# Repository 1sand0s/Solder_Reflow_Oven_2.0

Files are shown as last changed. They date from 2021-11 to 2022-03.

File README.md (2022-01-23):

# Solder Reflow Oven


 
<h2> What is it ? </h2>
A homebrew solder reflow oven controller designed around an STM32L053 series MCU with PCB layouting done in Kicad. A solder reflow oven is a device used to 
automatically solder SMD components. When dealing with integrated circuits designed to operate at high frequencies, their packages might not have leads solderable by
hand (leads can add unwanted inductance). Therefore, the only way to solder them is by using a solder reflow oven.  

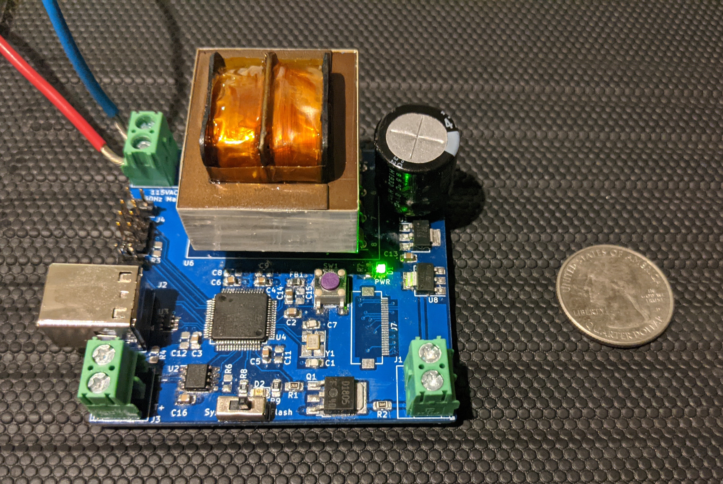
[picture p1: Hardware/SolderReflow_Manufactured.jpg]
 
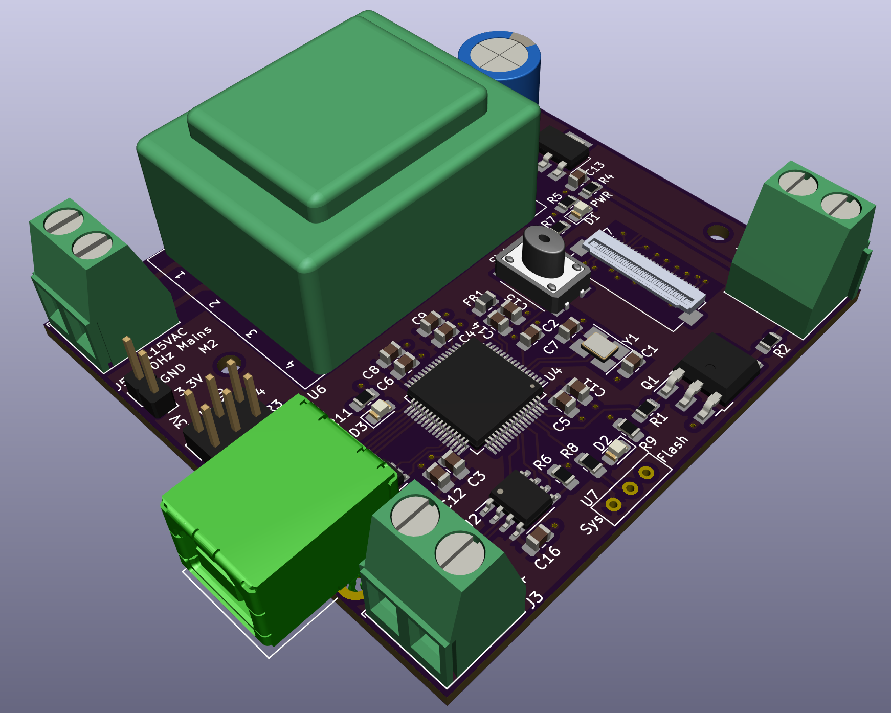
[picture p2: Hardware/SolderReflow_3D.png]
 

<h2> How does it work ? </h2>

1. The pads of the PCB are covered in solder paste, typically done with the help of a stencil

2. The components are then carefully placed on the board, the paste helps in providing adhesion to hold the components in place
 
3. The board is then placed inside the oven which controls the ambient temperature to follow a certain profile (specific to the solder paste used)
 
4. During this process the components get soldered onto the board

<h2> Heart of the Solder Reflow Oven </h2>
The heart of the solder reflow oven is the controller (the design included in this repo) which controls the ambient temperature inside the oven to follow the
specified profile. I use PID (Proportional Integrator Differentiator) control to control the ambient temperature.

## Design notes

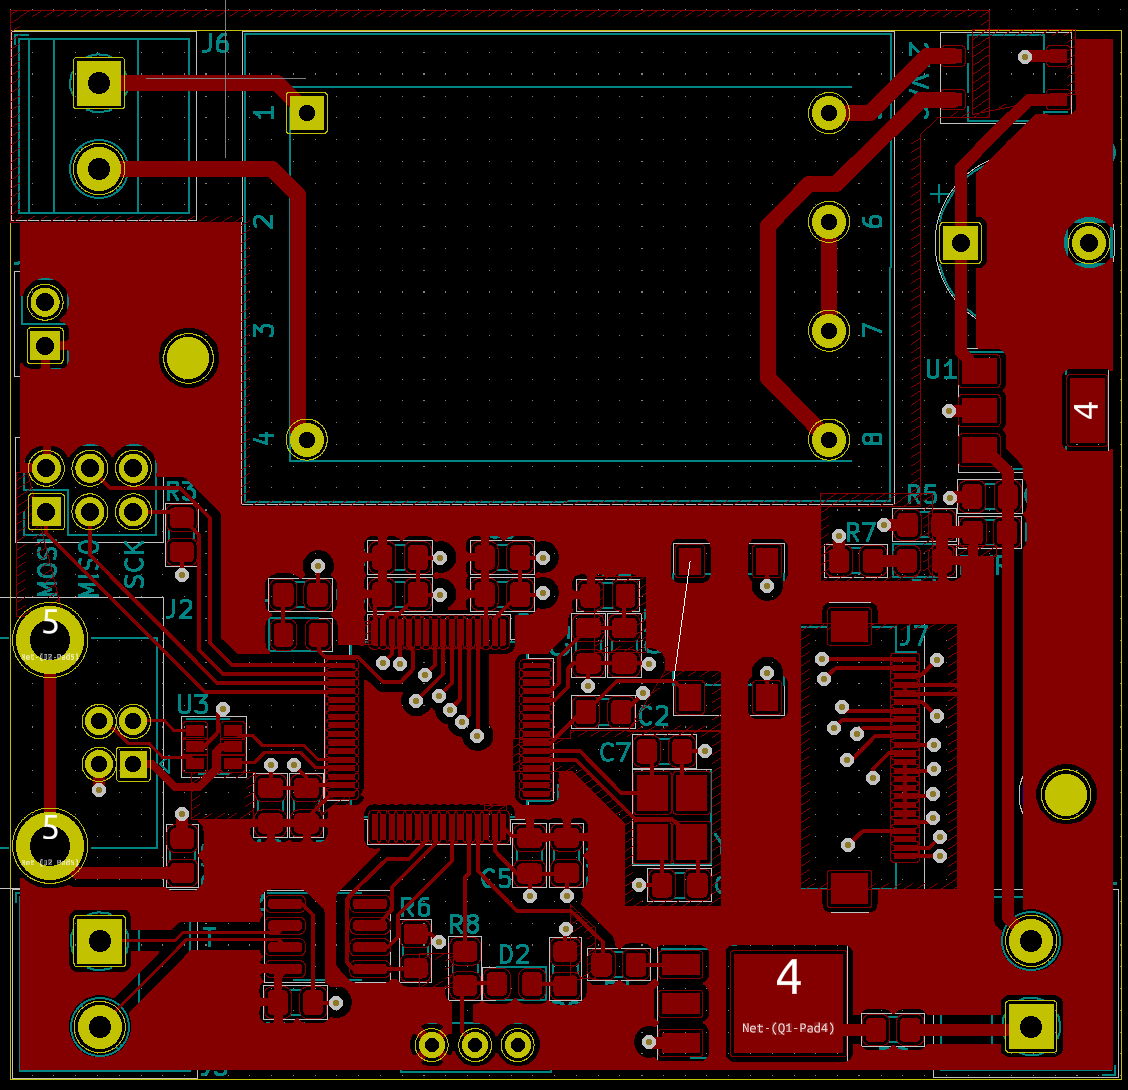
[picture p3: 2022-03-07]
Hardware/Fcu.png

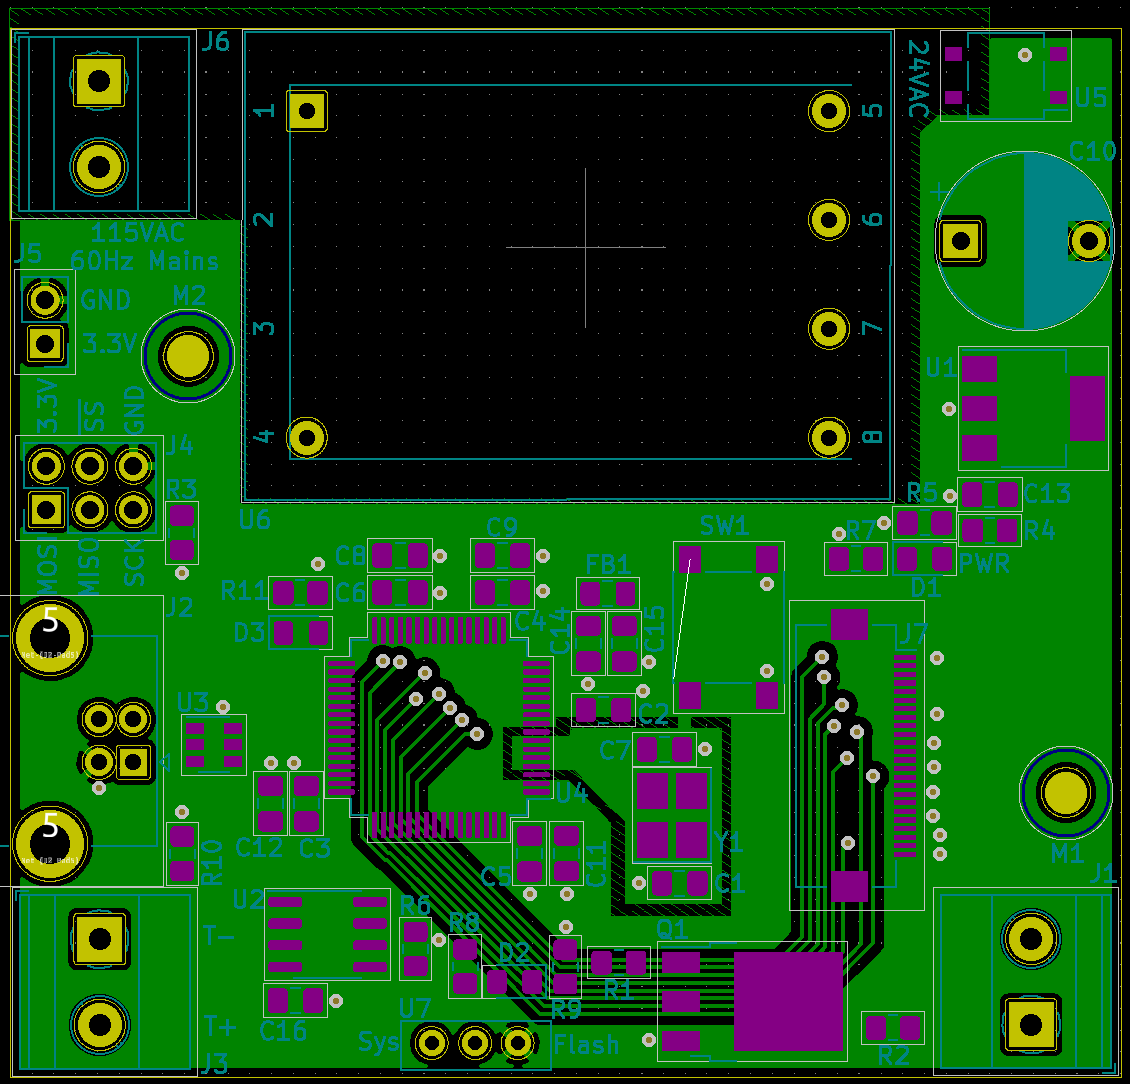
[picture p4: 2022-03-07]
Hardware/Bcu.png

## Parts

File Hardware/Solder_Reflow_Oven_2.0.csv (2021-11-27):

Id | Designator | Package | Quantity | Designation | Supplier and ref
1 | U4 | LQFP-64_10x10mm_P0.5mm | 1 | STM32L053R6T6
2 | U2 | SOIC-8_3.9x4.9mm_P1.27mm | 1 | MAX31855KASA
3 | J7 | Hirose_FH12-24S-0.5SH_1x24-1MP_P0.50mm_Horizontal | 1 | Conn_01x24_Male
4 | SW1 | SW_Push_1P1T_NO_6x6mm_H9.5mm | 1 | SW_DIP_x01
5 | C16,C2 | C_0603_1608Metric | 2 | 0.1uF
6 | R5,R7,R9 | R_0603_1608Metric_Pad0.98x0.95mm_HandSolder | 3 | 1k
7 | R4 | R_0603_1608Metric_Pad0.98x0.95mm_HandSolder | 1 | 2k
8 | C13 | C_0603_1608Metric | 1 | 22uF
9 | C10 | CP_Elec_10x14.3 | 1 | 470uF
10 | C15,C12,C11,C9,C8 | C_0603_1608Metric | 5 | 100nF
11 | C7,C1 | C_0603_1608Metric | 2 | 8pF
12 | C6,C5,C4,C3 | C_0603_1608Metric | 4 | 10uF
13 | J2 | USB_Micro-B_GCT_USB3076-30-A | 1 | USB_B_Micro
14 | FB1 | L_0402_1005Metric_Pad0.77x0.64mm_HandSolder | 1 | MMZ1005S601HTD25
15 | J1,J3,J6 | TerminalBlock_Phoenix_MKDS-1,5-2_1x02_P5.00mm_Horizontal | 3 | Conn_01x02_Male
16 | J4 | PinHeader_2x03_P2.54mm_Vertical_SMD | 1 | Conn_02x03_Top_Bottom
17 | Q1 | TO-252-3_TabPin4 | 1 | 2SD1805
18 | R1 | R_0603_1608Metric_Pad0.98x0.95mm_HandSolder | 1 | 260
19 | R2 | R_0603_1608Metric_Pad0.98x0.95mm_HandSolder | 1 | 653
20 | R3,R6,R8 | R_0603_1608Metric_Pad0.98x0.95mm_HandSolder | 3 | 10k
21 | U3 | SOT-23-6 | 1 | RCLAMP0502A.TCT
22 | U5 | TO-269AA | 1 | CDBHD140L-G
23 | Y1 | Crystal_SMD_3225-4Pin_3.2x2.5mm_HandSoldering | 1 | Crystal_GND24
24 | U1 | SOT-223 | 1 | LM2940IMPX-10/NOPB
25 | U6 | Transformer_Breve_TEZ-22x24 | 1 | F24-100-C2
26 | C14 | C_0603_1608Metric | 1 | 1uF
27 | J5 | PinHeader_1x02_P2.54mm_Vertical_SMD_Pin1Left | 1 | Conn_01x02_Top_Bottom
28 | D1,D2 | LED_0603_1608Metric_Pad1.05x0.95mm_HandSolder | 2 | LED
29 | U7 | SPDT_Reflow | 1 | SPDT_Reflow

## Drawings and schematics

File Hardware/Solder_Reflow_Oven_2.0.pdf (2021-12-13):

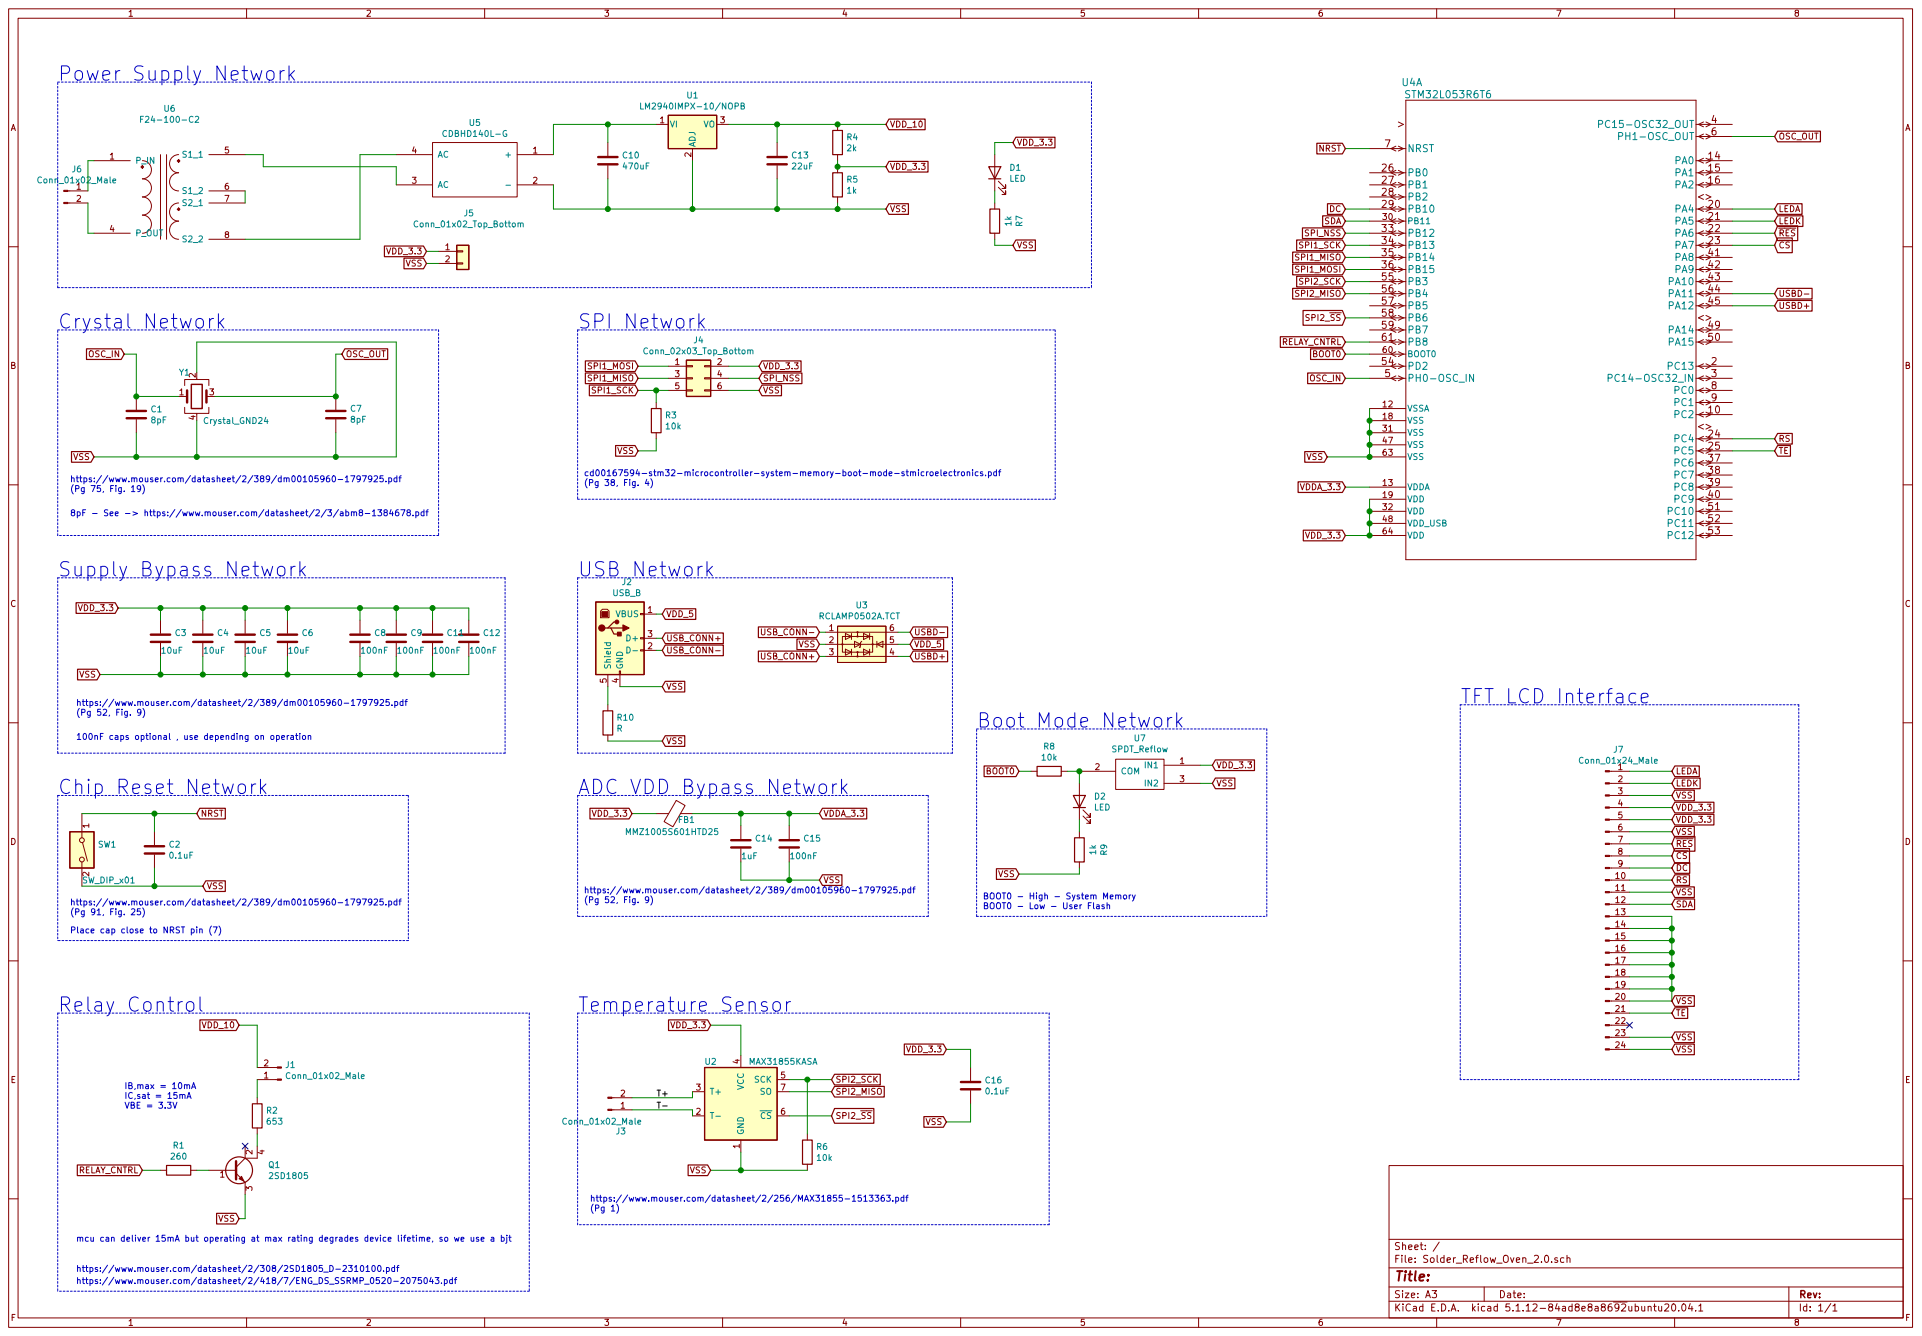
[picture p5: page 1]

https://www.mouser.com/datasheet/2/389/dm00105960-1797925.pdf
(Pg 75, Fig. 19)

cd00167594-stm32-microcontroller-system-memory-boot-mode-stmicroelectronics.pdf
(Pg 38, Fig. 4)

8pF - See -> https://www.mouser.com/datasheet/2/3/abm8-1384678.pdf

(Pg 52, Fig. 9)

100nF caps optional , use depending on operation
T+T- Chip Reset Network

ADC VDD Bypass Network

https://www.mouser.com/datasheet/2/389/dm00105960-1797925.pdf (Pg 52, Fig. 9)

BOOT0 - High - System Memory BOOT0 - Low - User Flash

(Pg 91, Fig. 25)
Place cap close to NRST pin (7)

https://www.mouser.com/datasheet/2/256/MAX31855-1513363.pdf

mcu can deliver 15mA but operating at max rating degrades device lifetime, so we use a bjt

https://www.mouser.com/datasheet/2/308/2SD1805_D-2310100.pdf
https://www.mouser.com/datasheet/2/418/7/ENG_DS_SSRMP_0520-2075043.pdf

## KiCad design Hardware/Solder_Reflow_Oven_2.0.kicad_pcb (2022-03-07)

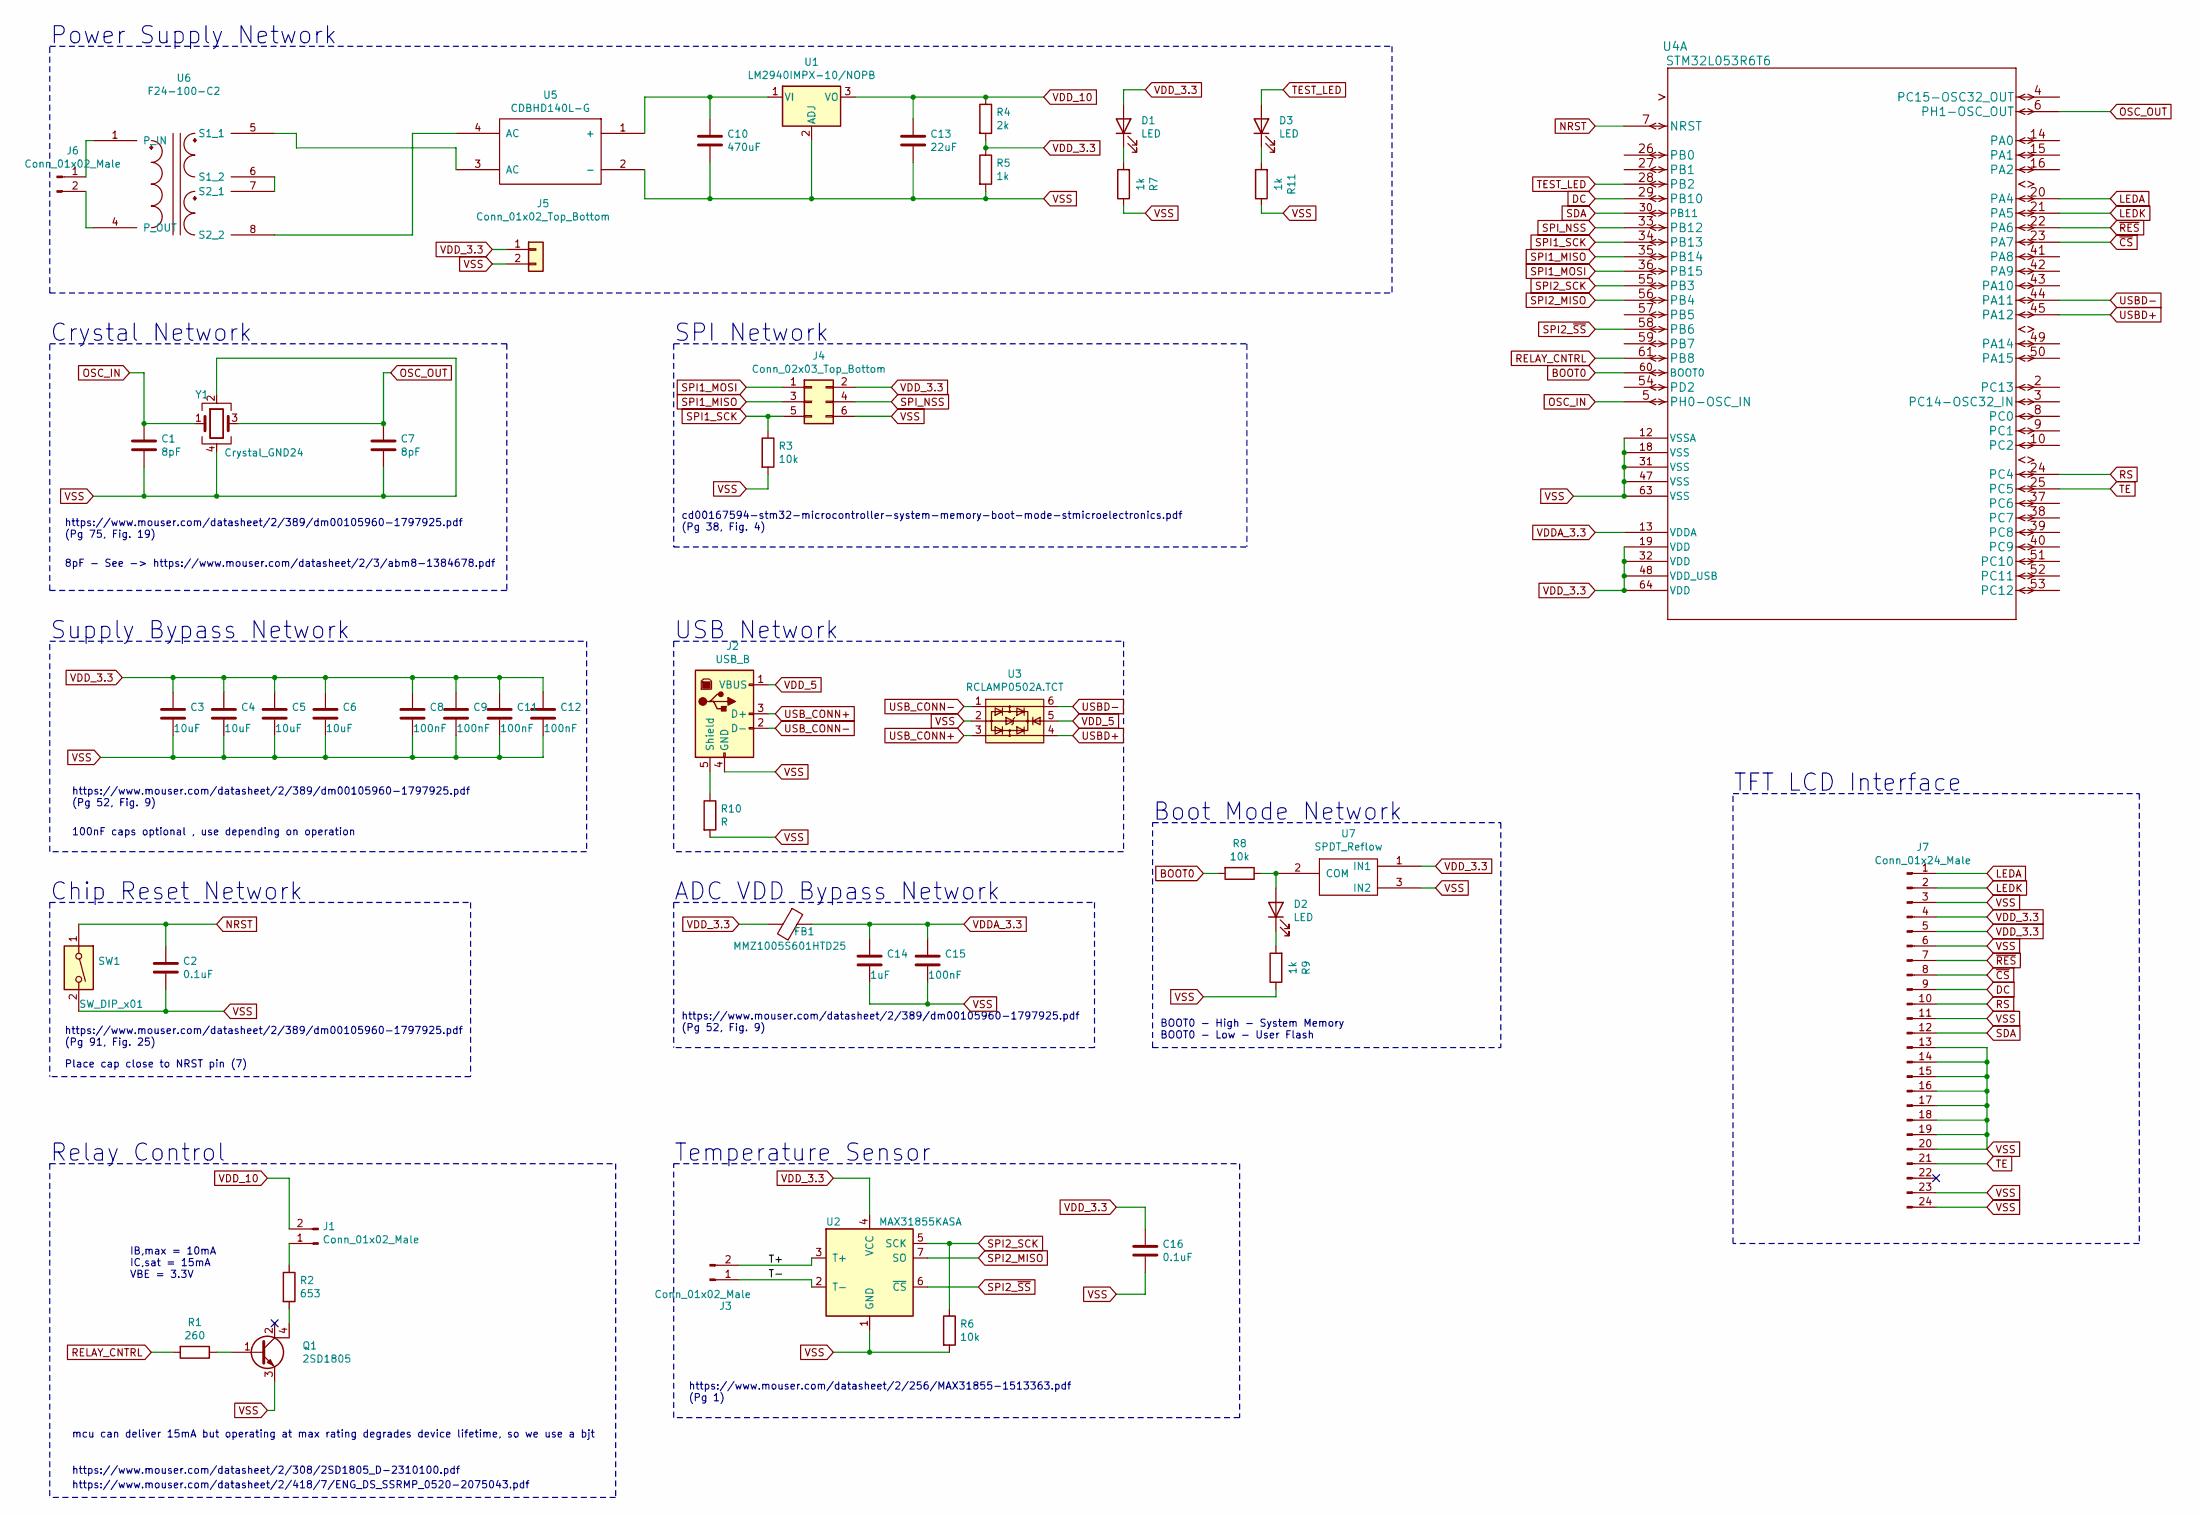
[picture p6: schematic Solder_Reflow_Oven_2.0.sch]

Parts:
C1, C7: 8pF; C_0805_2012Metric_Pad1.18x1.45mm_HandSolder
C2, C16: 0.1uF; C_0805_2012Metric_Pad1.18x1.45mm_HandSolder
C3, C4, C5, C6: 10uF; C_0805_2012Metric_Pad1.18x1.45mm_HandSolder
C8, C9, C11, C12, C15: 100nF; C_0805_2012Metric_Pad1.18x1.45mm_HandSolder
C10: 470uF; CP_Radial_D10.0mm_P7.50mm
C13: 22uF; C_0805_2012Metric_Pad1.18x1.45mm_HandSolder
C14: 1uF; C_0805_2012Metric_Pad1.18x1.45mm_HandSolder
D1, D2, D3: LED; LED_0805_2012Metric_Pad1.15x1.40mm_HandSolder
FB1: MMZ1005S601HTD25; L_0805_2012Metric_Pad1.15x1.40mm_HandSolder
J1, J3, J6: Conn_01x02_Male; TerminalBlock_Phoenix_MKDS-1,5-2_1x02_P5.00mm_Horizontal
J2: USB_B; USB_B_Lumberg_2411_02_Horizontal
J4: Conn_02x03_Top_Bottom; PinHeader_2x03_P2.54mm_Vertical
J5: Conn_01x02_Top_Bottom; PinHeader_1x02_P2.54mm_Vertical
J7: Conn_01x24_Male; Hirose_FH12-24S-0.5SH_1x24-1MP_P0.50mm_Horizontal
Q1: 2SD1805; TO-252-3_TabPin4
R1: 260; R_0805_2012Metric_Pad1.20x1.40mm_HandSolder
R2: 653; R_0805_2012Metric_Pad1.20x1.40mm_HandSolder
R3, R6, R8: 10k; R_0805_2012Metric_Pad1.20x1.40mm_HandSolder
R4: 2k; R_0805_2012Metric_Pad1.20x1.40mm_HandSolder
R5, R7, R9, R11: 1k; R_0805_2012Metric_Pad1.20x1.40mm_HandSolder
R10: R; R_0805_2012Metric_Pad1.20x1.40mm_HandSolder
SW1: SW_DIP_x01; SW_Push_1P1T_NO_6x6mm_H9.5mm
U1: LM2940IMPX-10/NOPB; SOT-223
U2: MAX31855KASA; SOIC-8_3.9x4.9mm_P1.27mm
U3: RCLAMP0502A.TCT; SOT-23-6
U4: STM32L053R6T6; LQFP-64_10x10mm_P0.5mm
U5: CDBHD140L-G; TO-269AA
U6: F24-100-C2; Transformer_Breve_TEZ-22x24
U7: SPDT_Reflow
Y1: Crystal_GND24; Crystal_SMD_3225-4Pin_3.2x2.5mm_HandSoldering

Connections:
/T+: J3.2, U2.3 (T+)
/T-: J3.1, U2.2 (T-)
BOOT0: R8.2, U4.60 (BOOT0)
DC: J7.9, U4.29 (PB10)
LEDA: J7.1, U4.20 (PA4)
LEDK: J7.2, U4.21 (PA5)
NRST: C2.1, SW1.1, U4.7 (NRST)
unnamed: C10.1, U1.1 (VI), U5.1 (+)
unnamed: D1.1 (K), R7.2
unnamed: D2.1 (K), R9.2
unnamed: D2.2 (A), R8.1, U7.2 (COM)
unnamed: D3.1 (K), R11.2
unnamed: J1.1, R2.1
unnamed: J2.5 (Shield), R10.1
unnamed: J6.1, U6.1 (P_IN)
unnamed: J6.2, U6.4 (P_OUT)
unnamed: Q1.1 (B), R1.1
unnamed: Q1.4 (C), R2.2
unnamed: D3.2 (A), U4.28 (PB2)
unnamed: U5.3 (AC), U6.5 (S1_1)
unnamed: U5.4 (AC), U6.8 (S2_2)
unnamed: U6.6 (S1_2), U6.7 (S2_1)
OSC_IN: C1.1, U4.5 (PH0-OSC_IN), Y1.1
OSC_OUT: C7.2, U4.6 (PH1-OSC_OUT), Y1.3
RELAY_CNTRL: R1.2, U4.61 (PB8)
RS: J7.10, U4.24 (PC4)
SDA: J7.12, U4.30 (PB11)
SPI1_MISO: J4.3, U4.35 (PB14)
SPI1_MOSI: J4.1, U4.36 (PB15)
SPI1_SCK: J4.5, R3.1, U4.34 (PB13)
SPI2_MISO: U2.7 (SO), U4.56 (PB4)
SPI2_SCK: R6.1, U2.5 (SCK), U4.55 (PB3)
SPI2_~SS: U2.6 (~CS~), U4.58 (PB6)
SPI_NSS: J4.4, U4.33 (PB12)
TE: J7.21, U4.25 (PC5)
USBD+: U3.4, U4.45 (PA12)
USBD-: U3.6, U4.44 (PA11)
USB_CONN+: J2.3 (D+), U3.3
USB_CONN-: J2.2 (D-), U3.1
VDDA_3.3: C14.1, C15.1, FB1.1, U4.13 (VDDA)
VDD_3.3: C3.1, C4.1, C5.1, C6.1, C8.1, C9.1, C11.1, C12.1, C16.1, D1.2 (A), FB1.2, J4.2, J5.1, J7.4, J7.5, R4.2, R5.1, U2.4 (VCC), U4.19 (VDD), U4.32 (VDD), U4.48 (VDD_USB), U4.64 (VDD), U7.1 (IN1)
VDD_5: J2.1 (VBUS), U3.5
VDD_10: C13.1, J1.2, R4.1, U1.3 (VO)
VSS: C1.2, C2.2, C3.2, C4.2, C5.2, C6.2, C7.1, C8.2, C9.2, C10.2, C11.2, C12.2, C13.2, C14.2, C15.2, C16.2, J2.4 (GND), J4.6, J5.2, J7.3, J7.6, J7.11, J7.13, J7.14, J7.15, J7.16, J7.17, J7.18, J7.19, J7.20, J7.23, J7.24, Q1.3 (E), R3.2, R5.2, R6.2, R7.1, R9.1, R10.2, R11.1, SW1.2, U1.2 (ADJ), U2.1 (GND), U3.2, U4.12 (VSSA), U4.18 (VSS), U4.31 (VSS), U4.47 (VSS), U4.63 (VSS), U5.2 (-), U7.3 (IN2), Y1.2, Y1.4
~CS: J7.8, U4.23 (PA7)
~RES: J7.7, U4.22 (PA6)

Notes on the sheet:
https://www.mouser.com/datasheet/2/389/dm00105960-1797925.pdf (Pg 75, Fig. 19)
8pF - See -> https://www.mouser.com/datasheet/2/3/abm8-1384678.pdf
Crystal Network
SPI Network
Supply Bypass Network
100nF caps optional , use depending on operation
https://www.mouser.com/datasheet/2/389/dm00105960-1797925.pdf (Pg 52, Fig. 9)
Place cap close to NRST pin (7)
Chip Reset Network
https://www.mouser.com/datasheet/2/389/dm00105960-1797925.pdf (Pg 91, Fig. 25)
USB Network
ADC VDD Bypass Network
cd00167594-stm32-microcontroller-system-memory-boot-mode-stmicroelectronics.pdf (Pg 38, Fig. 4)
https://www.mouser.com/datasheet/2/308/2SD1805_D-2310100.pdf
Relay Control
IB,max = 10mA IC,sat = 15mA VBE = 3.3V
mcu can deliver 15mA but operating at max rating degrades device lifetime, so we use a bjt
https://www.mouser.com/datasheet/2/418/7/ENG_DS_SSRMP_0520-2075043.pdf
https://www.mouser.com/datasheet/2/256/MAX31855-1513363.pdf (Pg 1)
Temperature Sensor
Power Supply Network
Boot Mode Network
BOOT0 - High - System Memory BOOT0 - Low - User Flash
TFT LCD Interface

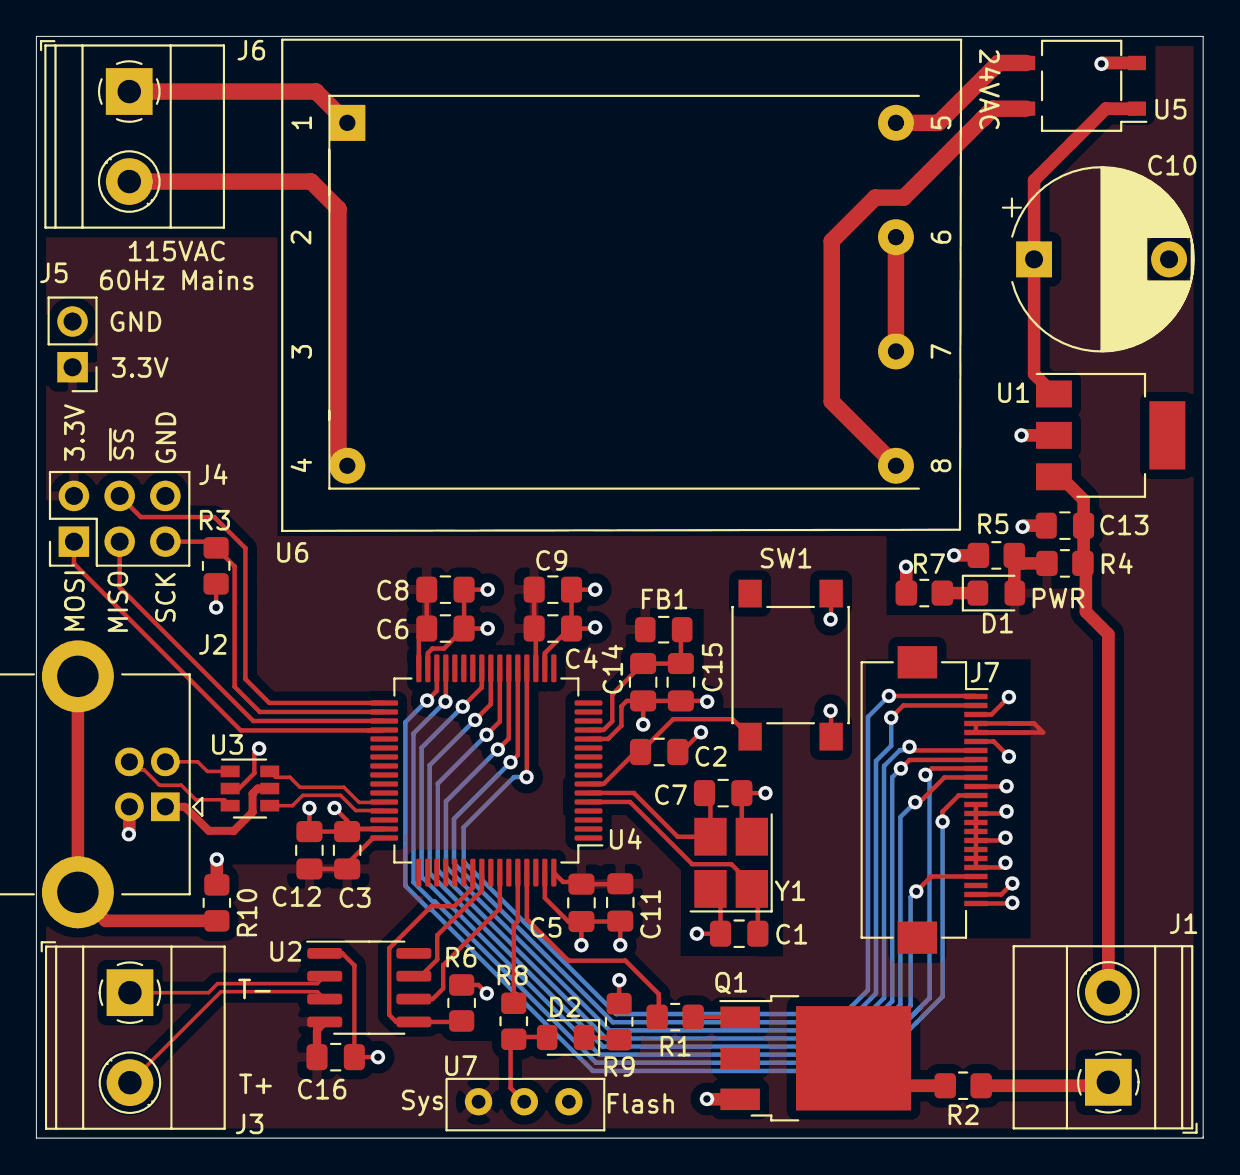
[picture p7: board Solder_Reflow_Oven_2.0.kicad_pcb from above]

Board: 2 copper layers, 64.8 x 61.2 mm, 46 parts (0 on the bottom side), 44 nets.

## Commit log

2021-11-27 Adding Schematic Files
    [Solder_Reflow_Oven_2.0.kicad_pcb, Solder_Reflow_Oven_2.0.sch]
2021-11-27 Adding BOM
    [Solder_Reflow_Oven_2.0.csv]
2021-12-13 Adding assembled board jpg
2021-12-13 Updating Design for through hole components
    [Solder_Reflow_Oven_2.0.kicad_pcb, Solder_Reflow_Oven_2.0.sch]
2021-12-13 adding new gerbers and layout images
2021-12-13 updating schematic pdf
2021-12-15 creating branch v1.1.1 for silkscreen readability
    [Solder_Reflow_Oven_2.0-B_Cu.gbr, Solder_Reflow_Oven_2.0-B_Mask.gbr, Solder_Reflow_Oven_2.0-B_Paste.gbr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]
2021-12-15 Updating kicad pcb file
    [Solder_Reflow_Oven_2.0.kicad_pcb]
2021-12-25 Updating board for version 2.0.0
    [Solder_Reflow_Oven_2.0-B_Cu.gbr, Solder_Reflow_Oven_2.0-B_Mask.gbr, Solder_Reflow_Oven_2.0-B_Paste.gbr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]
2021-12-25 Changing 3.3V supply from voltage divider to LDO
2021-12-25 adding support for USART
    [Solder_Reflow_Oven_2.0-B_Cu.gbr, Solder_Reflow_Oven_2.0-B_Mask.gbr, Solder_Reflow_Oven_2.0-B_Paste.gbr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]
2021-12-25 Moving to Hardware Folder
    [Solder_Reflow_Oven_2.0-B_Cu.gbr, Solder_Reflow_Oven_2.0-B_Mask.gbr, Solder_Reflow_Oven_2.0-B_Paste.gbr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]
2021-12-26 SPI header position change
    [Solder_Reflow_Oven_2.0.kicad_pcb]
2022-03-07 Updating board to include mounting holes and debugging LED
    [Solder_Reflow_Oven_2.0-B_Cu.gbr, Solder_Reflow_Oven_2.0-B_Mask.gbr, Solder_Reflow_Oven_2.0-B_Paste.gbr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]
